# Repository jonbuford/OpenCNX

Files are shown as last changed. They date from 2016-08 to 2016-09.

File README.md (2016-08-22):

# OpenCNX
OpenCNX Connection Standard for Modular Control Systems

The OpenCNX standard is for defining the interfaces between modules in a microcontroller system developed for automation. 
The first interfaces are: 

OpenCNX 164 - Used for connecting a microcontroller to an 8 function module backplane (at least that is the first use).

OpenCNX 34 - Function Module interface that combines both power and communication in a useful way. Think of Arduino or Raspberry Pi shields/hats with high voltage and current available. It also includes a system sync for supporting microcontrollers on the modules for things like advanced motion control.

This has initially been developed by Apparatus as part of the Atomotion line, but the intent is for it to be open for everyone to work with.

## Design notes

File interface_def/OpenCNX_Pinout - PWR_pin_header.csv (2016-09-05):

OpenCNX Standard Pinout |  |  | V0.1
Power | 64 pin header | General Assumptions: 3A Max Per Pin, 2A Steady State Max
Description | Pin Name | Header Pin (A) | Type | Description | Pin Name | Header Pin (B) | Type
5V Supply | V5_1 | 1 | Power | 5V Supply | V5_4 | 2 | Power
5V Supply | V5_2 | 3 | Power | 5V Supply | V5_5 | 4 | Power
5V Supply | V5_3 | 5 | Power | 5V Supply | V5_6 | 6 | Power
3.3V Supply | V3_1 | 7 | Power | 3.3V Supply | V3_4 | 8 | Power
3.3V Supply | V3_2 | 9 | Power | 3.3V Supply | V3_5 | 10 | Power
3.3V Supply | V3_3 | 11 | Power | 3.3V Supply | V3_6 | 12 | Power
Ground | GND1 | 13 | Power | Ground | GND2 | 14 | Power
Ground | GND3 | 15 | Power | Ground | GND4 | 16 | Power
Ground | GND5 | 17 | Power | Ground | GND6 | 18 | Power
Ground | GND7 | 19 | Power | Ground | GND8 | 20 | Power
Ground | GND9 | 21 | Power | Ground | GND10 | 22 | Power
Ground | GND11 | 23 | Power | Ground | GND12 | 24 | Power
Ground | GND13 | 25 | Power | Ground | GND14 | 26 | Power
Ground | GND15 | 27 | Power | Ground | GND16 | 28 | Power
Ground | GND17 | 29 | Power | Ground | GND18 | 30 | Power
Ground | GND19 | 31 | Power | Ground | GND20 | 32 | Power
Ground | GND21 | 33 | Power | Ground | GND22 | 34 | Power
12V Supply | V12_1 | 35 | Power | 12V Supply | V12_2 | 36 | Power
12V Supply | V12_3 | 37 | Power | 12V Supply | V12_4 | 38 | Power
12V Supply | V12_5 | 39 | Power | 12V Supply | V12_6 | 40 | Power
12V Supply | V12_7 | 41 | Power | 12V Supply | V12_8 | 42 | Power
12V Supply | V12_9 | 43 | Power | 12V Supply | V12_10 | 44 | Power
Vin | VIN1 | 45 | Power | Vin | VIN2 | 46 | Power
Vin | VIN3 | 47 | Power | Vin | VIN4 | 48 | Power
Vin | VIN5 | 49 | Power | Vin | VIN6 | 50 | Power
Vin | VIN7 | 51 | Power | Vin | VIN8 | 52 | Power
Vin | VIN9 | 53 | Power | Vin | VIN10 | 54 | Power
Vin | VIN11 | 55 | Power | Vin | VIN12 | 56 | Power
Vin | VIN13 | 57 | Power | Vin | VIN14 | 58 | Power
Vin | VIN15 | 59 | Power | Vin | VIN16 | 60 | Power
Vin | VIN17 | 61 | Power | Vin | VIN18 | 62 | Power
Vin | VIN19 | 63 | Power | Vin | VIN20 | 64 | Power

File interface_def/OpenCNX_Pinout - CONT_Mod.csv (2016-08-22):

OpenCNX Standard Pinout |  |  | V0.4
Control Module | 164 pin header | General Assumptions: 0.5A Max Steady State Current Draw, PCI-e standard header
Description | Pin Name | Header Pin (A) | Type, Notes | Description | Pin Name | Header Pin (B) | Type, Notes
12V Supply | V12_0 | A1 | Power, 1A Max @ 12V | Ground | GND1 | B1 | Power
12V Supply | V12_1 | A2 | Power | Ground | GND2 | B2 | Power
5V Supply | V5_0 | A3 | Power, 1A Max @ 5V | Ground | GND3 | B3 | Power
5V Supply | V5_1 | A4 | Power | Ground | GND4 | B4 | Power
3.3V Supply | V3_0 | A5 | Power, 1A Max @ 3.3V | Ground | GND5 | B5 | Power
3.3V Supply | V3_1 | A6 | Power | Ground | GND6 | B6 | Power
Ground | GND7 | A7 | Power | SPI MOSI | SPI_MOSI | B7 | Output
SPI SCLK | SPI_SCLK | A8 | Output | SPI MISO | SPI_MISO | B8 | Input
SPI SS | SPI_SS | A9 | Output | SPI SEL1 | SPI_SEL1 | B9 | Output
SPI SEL0 | SPI_SEL0 | A10 | Output | SPI SEL2 | SPI_SEL2 | B10 | Output
Ground | GND8 | A11 | Power | Ground | GND9 | B11 | Power
I2C SDA | I2C_SDA | A12 | I/O | I2C SCL | I2C_SCL | B12 | I/O
I2C SEL0 | I2C_SEL0 | A13 | Output | I2C SEL2 | I2C_SEL2 | B13 | Output
I2C SEL1 | I2C_SEL1 | A14 | Output | I2C SEL3 | I2C_SEL3 | B14 | Output
 |  | A15 |  |  |  | B15
 |  | A16 |  | Function Modules Reset | RESETN | B16 | Output
System Clock 16MHz | SYSCLKH | A17 | Output |  |  | B17
 |  | A18 |  | System Sync Clock | SYSSYNC | B18 | Output
 |  | A19 |  |  |  | B19
Ground | GND10 | A20 | Power | Ground | GND11 | B20 | Power
ADC Input | ADC0_S | A21 | Analog Input | ADC Input | ADC1_S | B21 | Analog Input
 |  | A22 |  |  |  | B22
PWM Output | PWM0_S | A23 | I/O, Casing | PWM Output (Fan, LED, etc.) | PWM1_S | B23 | I/O, Casing
GPIO | GPIO0_S | A24 | I/O, Casing | GPIO | GPIO1_S | B24 | I/O, Casing
Ground | GND12 | A25 | Power | Ground | GND13 | B25 | Power
PWM Output | PWM0_0 | A26 | I/O, Function Header 0 | PWM Output | PWM1_0 | B26 | I/O, Function Header 0
GPIO | GPIO0_0 | A27 | I/O, Function Header 0 | GPIO | GPIO3_0 | B27 | I/O, Function Header 0
GPIO | GPIO1_0 | A28 | I/O, Function Header 0 | GPIO | GPIO4_0 | B28 | I/O, Function Header 0
GPIO | GPIO2_0 | A29 | I/O, Function Header 0 | GPIO | GPIO5_0 | B29 | I/O, Function Header 0
 |  | A30 | I/O, Function Header 0 |  |  | B30 | I/O, Function Header 0
ADC/GPIO | ADC0_0 | A31 | I/O, Function Header 0 | ADC/GPIO | ADC1_0 | B31 | I/O, Function Header 0
Ground | GND14 | A32 | Power | Ground | GND15 | B32 | Power
PWM Output | PWM0_1 | A33 | I/O, Function Header 1 | PWM Output | PWM1_1 | B33 | I/O, Function Header 1
GPIO | GPIO0_1 | A34 | I/O, Function Header 1 | GPIO | GPIO3_1 | B34 | I/O, Function Header 1
GPIO | GPIO1_1 | A35 | I/O, Function Header 1 | GPIO | GPIO4_1 | B35 | I/O, Function Header 1
GPIO | GPIO2_1 | A36 | I/O, Function Header 1 | GPIO | GPIO5_1 | B36 | I/O, Function Header 1
 |  | A37 | I/O, Function Header 1 |  |  | B37 | I/O, Function Header 1
ADC/GPIO | ADC0_1 | A38 | I/O, Function Header 1 | ADC/GPIO | ADC1_1 | B38 | I/O, Function Header 1
Ground | GND16 | A39 | Power | Ground | GND17 | B39 | Power
PWM Output | PWM0_2 | A40 | I/O, Function Header 2 | PWM Output | PWM1_2 | B40 | I/O, Function Header 2
GPIO | GPIO0_2 | A41 | I/O, Function Header 2 | GPIO | GPIO3_2 | B41 | I/O, Function Header 2
GPIO | GPIO1_2 | A42 | I/O, Function Header 2 | GPIO | GPIO4_2 | B42 | I/O, Function Header 2
GPIO | GPIO2_2 | A43 | I/O, Function Header 2 | GPIO | GPIO5_2 | B43 | I/O, Function Header 2
 |  | A44 | I/O, Function Header 2 |  |  | B44 | I/O, Function Header 2
ADC/GPIO | ADC0_2 | A45 | I/O, Function Header 2 | ADC/GPIO | ADC1_2 | B45 | I/O, Function Header 2
Ground | GND18 | A46 | Power | Ground | GND19 | B46 | Power
PWM Output | PWM0_3 | A47 | I/O, Function Header 3 | PWM Output | PWM1_3 | B47 | I/O, Function Header 3
GPIO | GPIO0_3 | A48 | I/O, Function Header 3 | GPIO | GPIO3_3 | B48 | I/O, Function Header 3
GPIO | GPIO1_3 | A49 | I/O, Function Header 3 | GPIO | GPIO4_3 | B49 | I/O, Function Header 3
GPIO | GPIO2_3 | A50 | I/O, Function Header 3 | GPIO | GPIO5_3 | B50 | I/O, Function Header 3
 |  | A51 | I/O, Function Header 3 |  |  | B51 | I/O, Function Header 3
ADC/GPIO | ADC0_3 | A52 | I/O, Function Header 3 | ADC/GPIO | ADC1_3 | B52 | I/O, Function Header 3
Ground | GND20 | A39 | Power | Ground | GND21 | B39 | Power
PWM Output | PWM0_4 | A54 | I/O, Function Header 4 | PWM Output | PWM1_4 | B54 | I/O, Function Header 4
GPIO | GPIO0_4 | A55 | I/O, Function Header 4 | GPIO | GPIO3_4 | B55 | I/O, Function Header 4
GPIO | GPIO1_4 | A56 | I/O, Function Header 4 | GPIO | GPIO4_4 | B56 | I/O, Function Header 4
GPIO | GPIO2_4 | A57 | I/O, Function Header 4 | GPIO | GPIO5_4 | B57 | I/O, Function Header 4
 |  | A58 | I/O, Function Header 4 |  |  | B58 | I/O, Function Header 4
ADC/GPIO | ADC0_4 | A59 | I/O, Function Header 4 | ADC/GPIO | ADC1_4 | B59 | I/O, Function Header 4
Ground | GND22 | A39 | Power | Ground | GND23 | B39 | Power
PWM Output | PWM0_5 | A61 | I/O, Function Header 5 | PWM Output | PWM1_5 | B61 | I/O, Function Header 5
GPIO | GPIO0_5 | A62 | I/O, Function Header 5 | GPIO | GPIO3_5 | B62 | I/O, Function Header 5
GPIO | GPIO1_5 | A63 | I/O, Function Header 5 | GPIO | GPIO4_5 | B63 | I/O, Function Header 5
GPIO | GPIO2_5 | A64 | I/O, Function Header 5 | GPIO | GPIO5_5 | B64 | I/O, Function Header 5
 |  | A65 | I/O, Function Header 5 |  |  | B65 | I/O, Function Header 5
ADC/GPIO | ADC0_5 | A66 | I/O, Function Header 5 | ADC/GPIO | ADC1_5 | B66 | I/O, Function Header 5
Ground | GND24 | A39 | Power | Ground | GND25 | B39 | Power
PWM Output | PWM0_6 | A68 | I/O, Function Header 6 | PWM Output | PWM1_6 | B68 | I/O, Function Header 6
GPIO | GPIO0_6 | A69 | I/O, Function Header 6 | GPIO | GPIO3_6 | B69 | I/O, Function Header 6
GPIO | GPIO1_6 | A70 | I/O, Function Header 6 | GPIO | GPIO4_6 | B70 | I/O, Function Header 6
GPIO | GPIO2_6 | A71 | I/O, Function Header 6 | GPIO | GPIO5_6 | B71 | I/O, Function Header 6
 |  | A72 | I/O, Function Header 6 |  |  | B72 | I/O, Function Header 6
ADC/GPIO | ADC0_6 | A73 | I/O, Function Header 6 | ADC/GPIO | ADC1_6 | B73 | I/O, Function Header 6
Ground | GND26 | A39 | Power | Ground | GND27 | B39 | Power
PWM Output | PWM0_7 | A75 | I/O, Function Header 7 | PWM Output | PWM1_7 | B75 | I/O, Function Header 7
GPIO | GPIO0_7 | A76 | I/O, Function Header 7 | GPIO | GPIO3_7 | B76 | I/O, Function Header 7
GPIO | GPIO1_7 | A77 | I/O, Function Header 7 | GPIO | GPIO4_7 | B77 | I/O, Function Header 7
GPIO | GPIO2_7 | A78 | I/O, Function Header 7 | GPIO | GPIO5_7 | B78 | I/O, Function Header 7
 |  | A79 | I/O, Function Header 7 |  |  | B79 | I/O, Function Header 7
ADC/GPIO | ADC0_7 | A80 | I/O, Function Header 7 | ADC/GPIO | ADC1_7 | B80 | I/O, Function Header 7
Ground | GND28 | A39 | Power | Ground | GND29 | B39 | Power
 |  | A82 |  |  |  | B82

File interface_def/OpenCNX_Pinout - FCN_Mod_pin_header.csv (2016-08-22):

OpenCNX Standard Pinout |  |  | V0.4
Function Module | 34 pin header | General Assumptions: 3A Max Per Pin, 2A Steady State Max
Description | Pin Name | Header Pin (A) | Type | Description | Pin Name | Header Pin (B) | Type
5V Supply | V5 | 1 | Power | 3.3V Supply | V3 | 2 | Power
Ground | GND1 | 3 | Power | ADC/GPIO | ADC0 | 4 | I/O, Analog
SPI MISO | SPI_MISO | 5 | Output | Ground | GND2 | 6 | Power
SPI MOSI | SPI_MOSI | 7 | Input | Ground | GND3 | 8 | Power
SPI SCLK | SPI_SCLK | 9 | Input | Ground | GND4 | 10 | Power
SPI SS | SPI_SS | 11 | Input | I2C SDA | I2C_SDA | 12 | I/O
Ground | GND5 | 13 | Power | I2C SCL | I2C_SCL | 14 | Input
System Clock 16MHz | SYSCLKH | 15 | Input | Board Reset | RESETN | 16 | Input
GPIO | GPIO4 | 17 | I/O | System Sync Clock | SYSSYNC | 18 | Input
GPIO | GPIO5 | 19 | I/O | GPIO | GPIO0 | 20 | I/O
PWM Output | PWM0 | 21 | I/O | GPIO | GPIO1 | 22 | I/O
PWM Output | PWM1 | 23 | I/O | GPIO | GPIO2 | 24 | I/O
ADC/GPIO | ADC1 | 25 | I/O, Analog | GPIO | GPIO3 | 26 | I/O
Ground | GND6 | 27 | Power | Ground | GND7 | 28 | Power
12V Supply | V12_1 | 29 | Power | 12V Supply | V12_2 | 30 | Power
Vin | VIN1 | 31 | Power | Vin | VIN2 | 32 | Power
Vin | VIN3 | 33 | Power | Vin | VIN4 | 34 | Power

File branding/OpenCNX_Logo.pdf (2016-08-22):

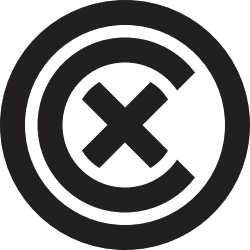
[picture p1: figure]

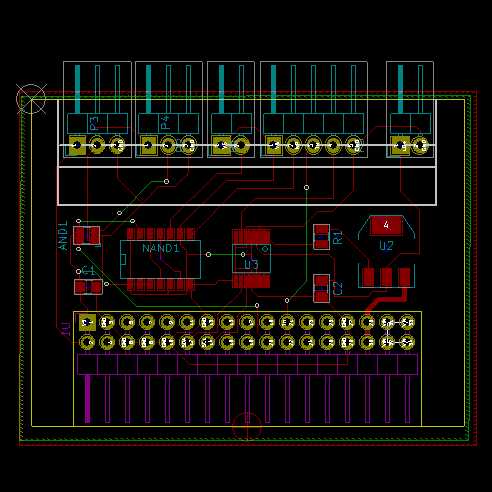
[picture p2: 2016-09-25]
templates/OpenCNX_34_Module/kicad/Sample-Project-Design/Sample PCB_Laser Module.png

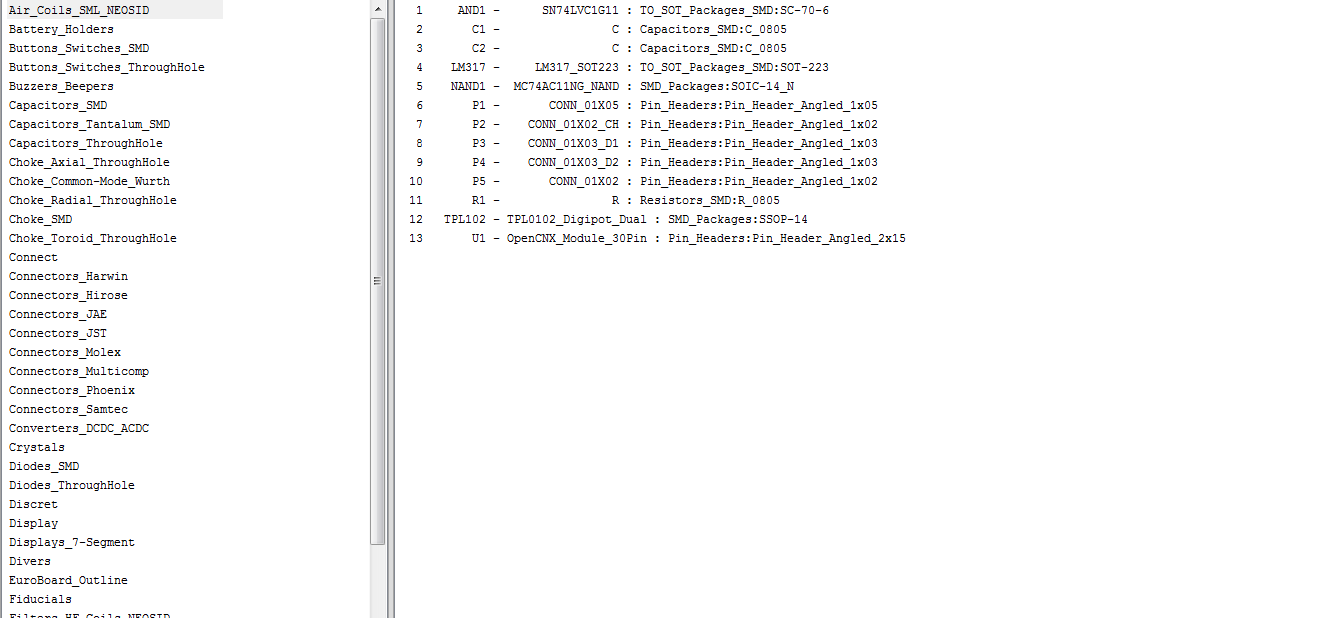
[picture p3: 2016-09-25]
templates/OpenCNX_34_Module/kicad/Sample-Project-Design/Sample Footprints List_Laser Module.png

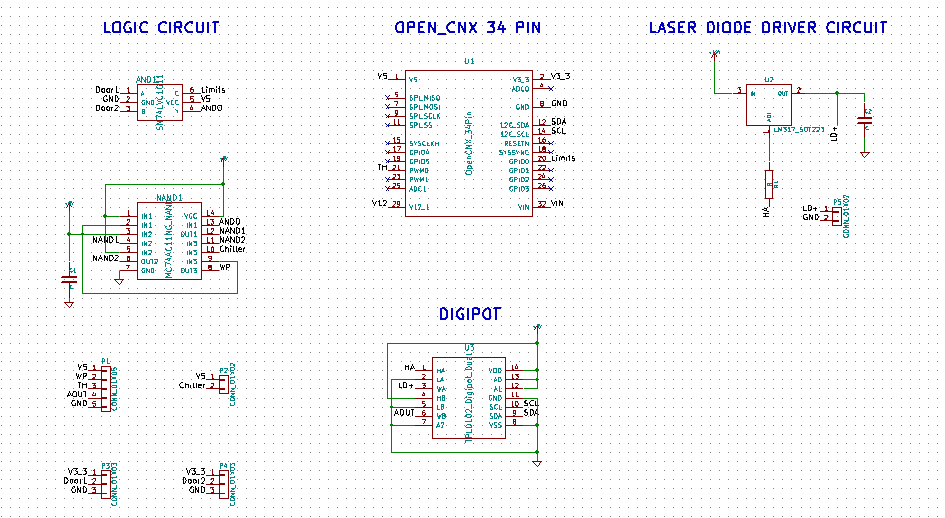
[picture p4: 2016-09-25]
templates/OpenCNX_34_Module/kicad/Sample-Project-Design/Sample Schematics_Laser Module.png

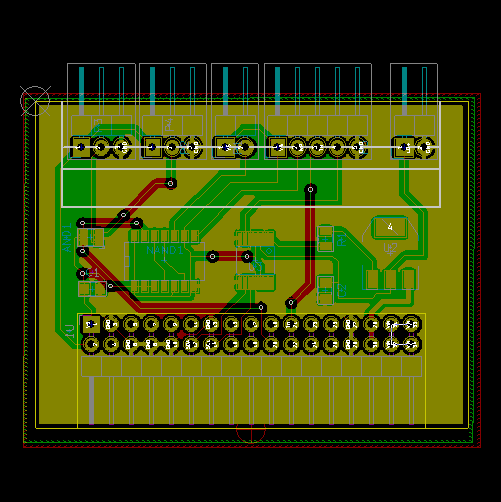
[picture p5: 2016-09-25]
templates/OpenCNX_34_Module/kicad/Sample-Project-Design/Sample PCB 2_Laser Module.png

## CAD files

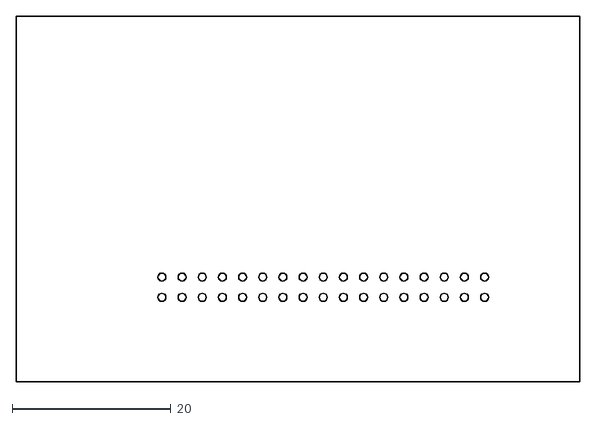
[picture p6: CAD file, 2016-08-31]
interface_def/OpenCNX34_Function_Modules_Mechanical_Spec.DXF
71.0 x 46.0

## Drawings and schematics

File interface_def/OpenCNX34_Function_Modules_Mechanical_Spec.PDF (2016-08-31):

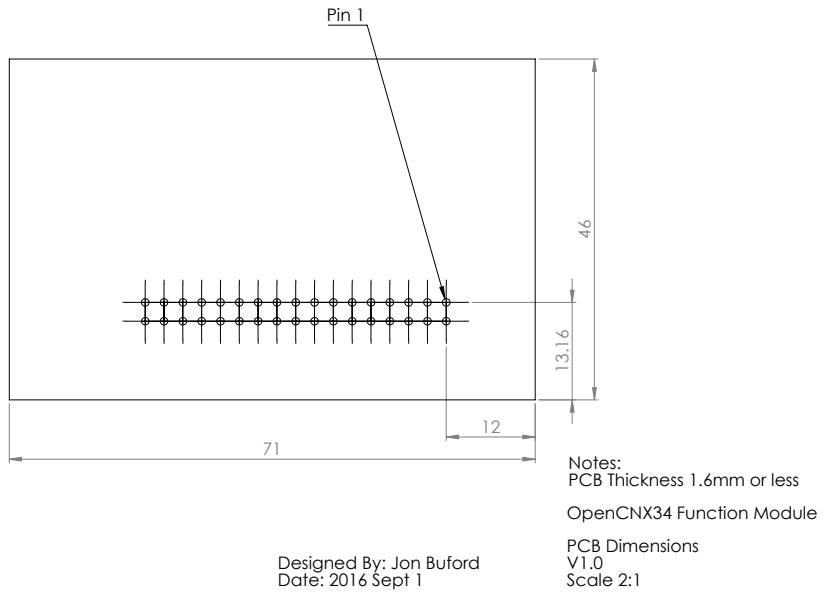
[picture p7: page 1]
Pin 1

Notes:
PCB Thickness 1.6mm or less
OpenCNX34 Function Module
PCB Dimensions
Scale 2:1

Designed By: Jon Buford
Date: 2016 Sept 1

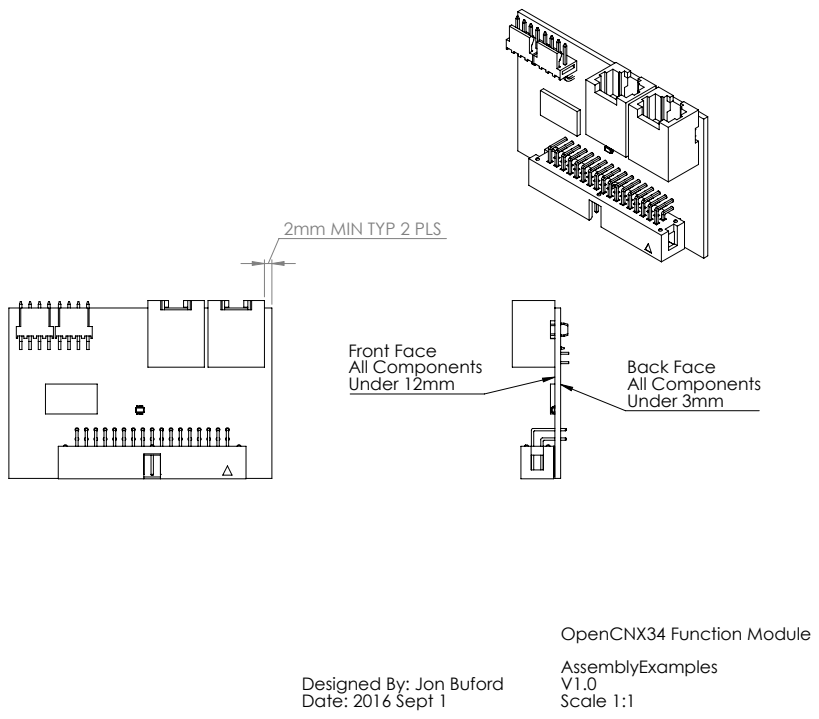
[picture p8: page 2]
Front Face All Components Under 12mm; Back Face All Components Under 3mm; OpenCNX34 Function Module; Scale 1:1

2mm MIN TYP 2 PLS

Designed By: Jon Buford
Date: 2016 Sept 1

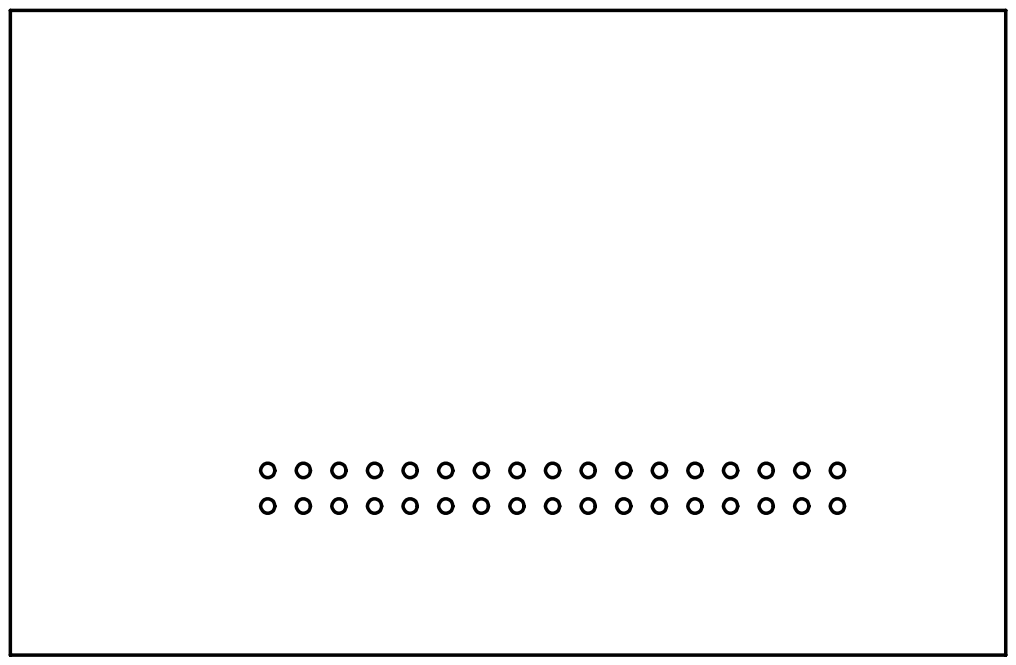
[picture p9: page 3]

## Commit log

2016-08-22 Moving standard docs into interface_def.
    [OpenCNX_Pinout - CONT_Mod.csv, OpenCNX_Pinout - FCN_Mod_pin_header.csv]
2016-08-22 KiCAD template project files
    This is the first set of KiCAD template project files with OpenCNX 3 pin
    component and footprint, along with the PCB layout. This will be used to
    design the function modules.
    [template.kicad_pcb, template.sch]
2016-08-24 KiCAD project files with OpenCNX component and PCB layout for Function Modules
    This project gives you all the basic resources to design your own
    functional module for Atomotion. This is the first set of template
    including OpenCNX 34 pin component and its footprint, along with the
    standard PCB layout.
    [template.kicad_pcb, template.sch]
2016-08-24 Organizing the template files
    Moving things around so that we can have more templates.
    [template.kicad_pcb, template.sch]
2016-08-24 Renaming the Template folder to templates
    [template.kicad_pcb, template.sch]
2016-08-31 Function Module PCB Spec and Application
    Spec for the size and usage of the PCB of the OpenCNX34 based function modules.
    [OpenCNX34_Function_Modules_Mechanical_Spec.DXF]
2016-09-05 Adding Power Interface (V0.1)
    Broke the power input out from the backplane so that we don't need to embed the power conditioning into the backplane and make a cleaner airflow in the whole thing. This will allow for ITX supply input and similar without having power conditioning or to have specific power input boards with a matching power conditioning.
    [OpenCNX_Pinout - PWR_pin_header.csv]
2016-09-25 Create Sample Project Design
